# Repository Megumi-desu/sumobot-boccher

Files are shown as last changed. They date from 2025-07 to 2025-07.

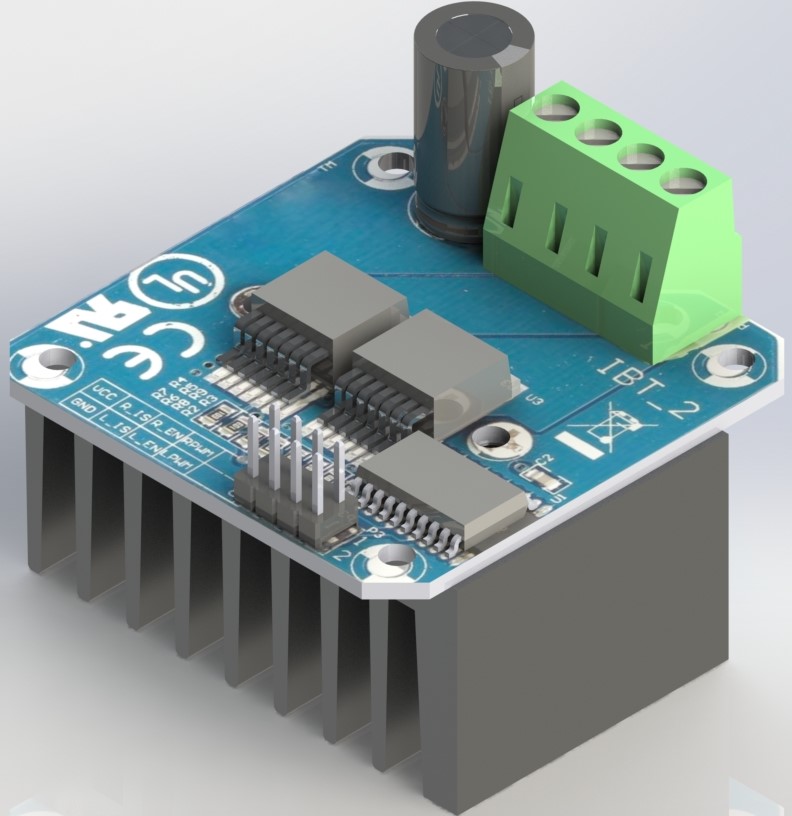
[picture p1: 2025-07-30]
Mechanic Design/BTS7960 43A HIGH POWER H BRIDGE MODULE.JPG

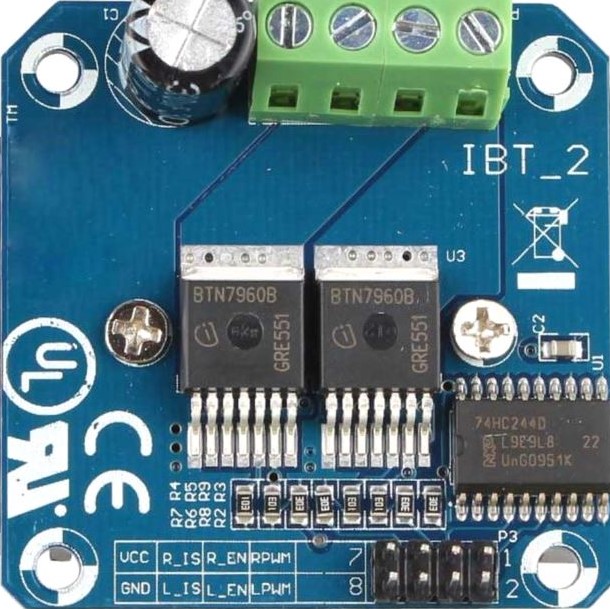
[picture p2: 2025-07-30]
Mechanic Design/TOP VIEW, BTS7960 43A HIGH POWER H BRIDGE MODULE.JPG

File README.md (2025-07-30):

# 🥊 SumoBot-Boccher  
**Arduino IDE Code for a 2-Wheel ESP32 Sumo Robot – Full RC Control**

> Ready-to-win firmware for TechnoCorner 2025!  
> Built around **ESP32 + L298N Dual H-Bridge + 2.4 GHz RC Rx/Tx**

---

## 📁 Repository Structure
```
sumobot-boccher/
├── README.md               ← You are here
├── boccher_v3_RC/          ← Final release v3 (RC)
│   └── boccher_v3_RC.ino   
└── extras/                 ← CAD, tuning logs, etc
```

---

## 🧰 Hardware Stack
| Part | Model / Pinout |
|---|---|
| Microcontroller | **ESP32 DOIT DevKit v1** |
| Motor Driver | **L298N Dual H-Bridge** |
| Motors | **JGA25-370** 12 V 500 rpm (3 kg robot) |
| RC System | **4-CH 2.4 GHz (FlySky TX4 clone)** |
| Battery | 3 S Li-ion 11.1 V 2200 mAh |
| Chassis | 3 mm aluminium plate, 3D-printed wheels |

---

## 🔌 Quick Wiring
| L298N | ESP32 Pin | Function |
|---|---|---|
| IN1 | 32 | Right motor direction 1 |
| IN2 | 33 | Right motor direction 2 |
| ENA | 25 | Right PWM (Channel 0) |
| IN3 | 27 | Left motor direction 1 |
| IN4 | 14 | Left motor direction 2 |
| ENB | 12 | Left PWM (Channel 1) |

| RC Rx | ESP32 Pin | Channel |
|---|---|---|
| CH1 | 5 | **Steering** |
| CH2 | 17 | **Throttle** |
| CH3 | 16 | **Rotate mode switch** |
| CH4 | 4 | **Emergency stop** |

> ⚡ Power the L298N logic from **5 V** rail, **NOT** 3.3 V.

---

## 🚀 Flash & Run
1. Install **Arduino IDE 2.x** with ESP32 board package (`esp32 by Espressif`).
2. Clone or download this repo.
3. Open `boccher_v2_RC/boccher_v3_RC.ino`.
4. Select:
   - Board: `ESP32 Dev Module`
   - Upload Speed: `921600`
   - Port: your COMx / ttyUSBx
5. Upload.
6. Power on the robot **then** the RC transmitter.
7. Open Serial Monitor @ 115 200 baud to see live telemetry.

---

## 🎮 RC Control Logic
| Stick / Switch | Behavior |
|---|---|
| **Left stick (CH2)** | Throttle forward / backward |
| **Right stick (CH1)** | Steering (tank mixing) |
| **3-pos switch (CH3)** | Up = **Rotate mode**<br>Middle = Normal drive<br>Down = N/A |
| **Momentary switch (CH4)** | Press = **Emergency stop** |

---

## 🛠 Tuning & Calibration
Calibrate your own sticks once:
```cpp
calibrateRC();   // Uncomment line 367, upload, follow Serial prompts
```
The sketch will print new `RC_CHx_CENTER` values – paste them back into the defines.

---

## 🧪 Built-in Test Routines
```cpp
testMotors();    // Line 350 → Full L298N motor test forward / backward
```
Great first-run sanity check.

---

## 🖥 Serial Debug Output (500 ms)
```
========== DEBUG INFO ==========
RC Connected: YES
Current Mode: NORMAL_DRIVE
--- RC Channels (Raw) ---
CH1 (Steering): 1670 | Mapped: 80
CH2 (Throttle): 1350 | Mapped: -110
CH3 (Rotate): 1500
CH4 (E-Stop): 1900
--- Motor Speeds ---
Right Motor: -190
Left Motor: -30
...
```

---

## 🏆 Competition Tips
- Set `speedMultiplier` (line 50) to 70–80 % during practice, 100 % on fight day.  
- Use **CH4 emergency stop** for instant failsafe.  
- Enable **debugMode = false** before matches to reduce latency.

---

## 🤝 Contributions & Forks
Pull requests welcome!  
🪲 Issues → GitHub Issues tab  
📸 Tag us on Instagram `#bocchersumo`

---

## 📄 License
MIT – do whatever you want, just mention the team 😉

---

**Built with ❤️ by Boccher Team – TechnoCorner 2025**  
> “*The ring is ours, the code is open.*”

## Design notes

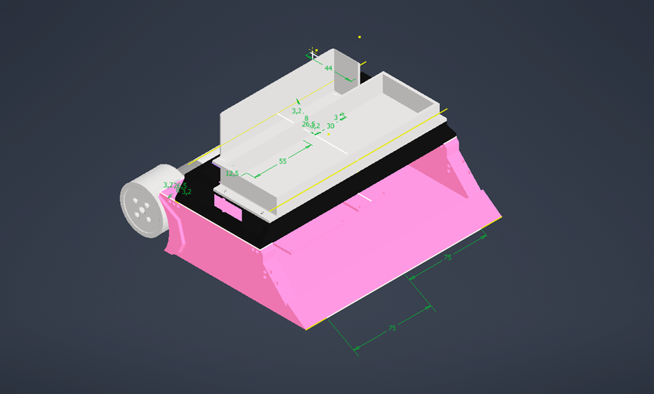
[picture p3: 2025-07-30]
design.png

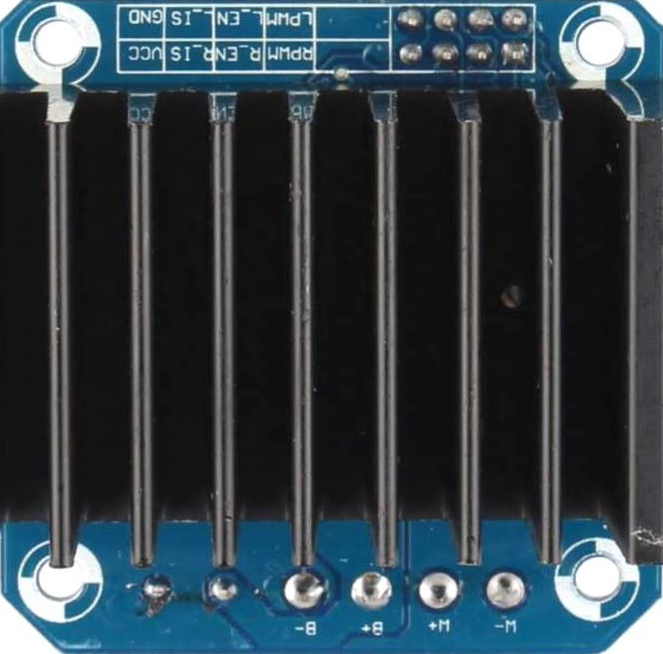
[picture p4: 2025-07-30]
Mechanic Design/BOTTOM VIEW, BTS7960 43A HIGH POWER H BRIDGE MODULE.JPG

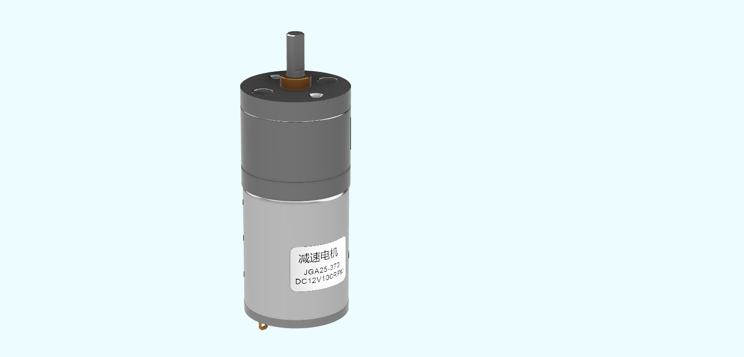
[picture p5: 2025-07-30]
Mechanic Design/JGA25-370 .png

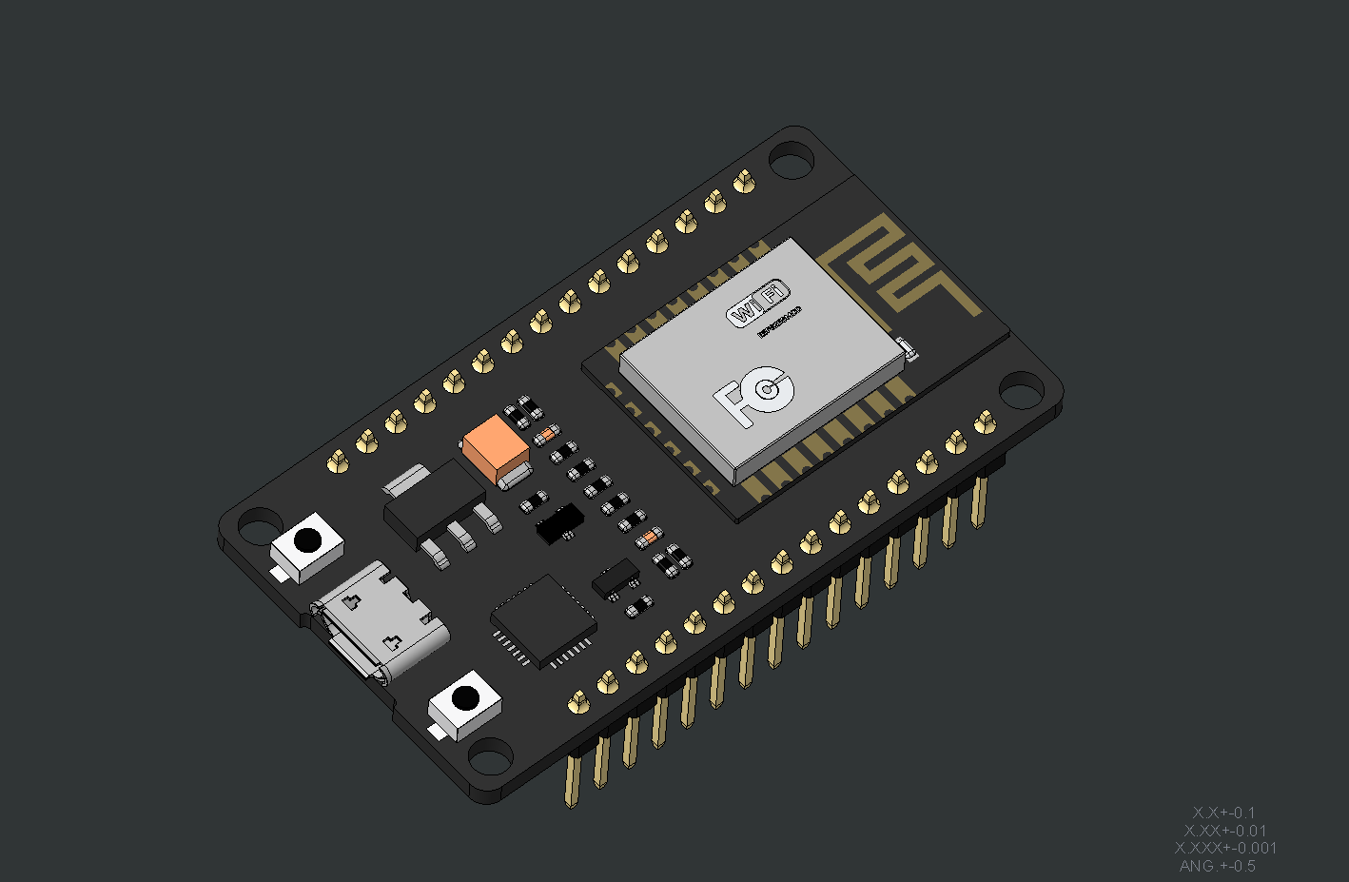
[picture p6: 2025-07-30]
Mechanic Design/esp32_dev_kit_v1.png

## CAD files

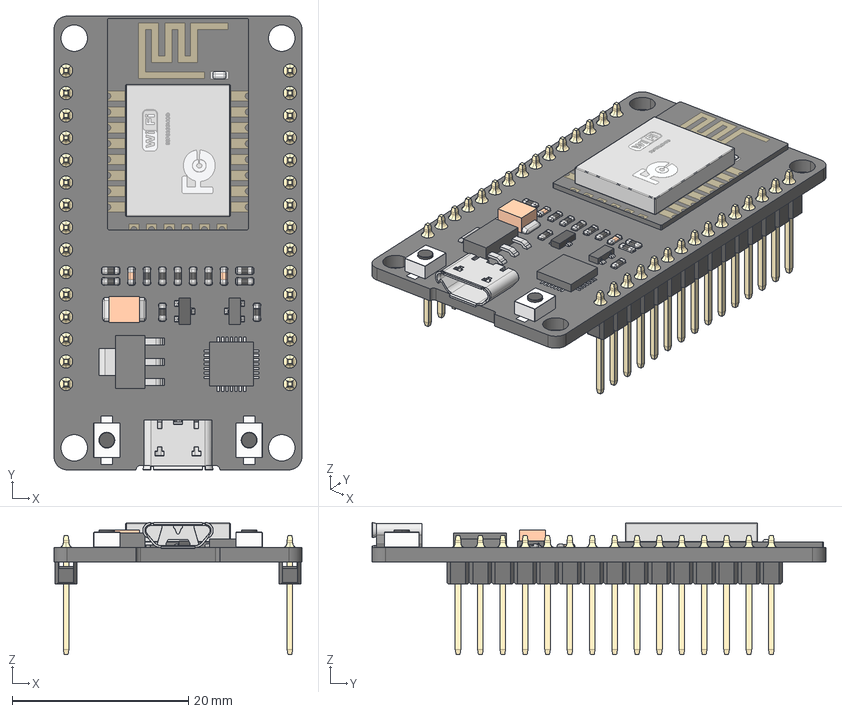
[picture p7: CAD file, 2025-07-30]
Mechanic Design/esp32_dev_kit_v1_asm.stp
28.1 x 51.5 x 15.0 mm
PCB
PIN x 30
WIFI_CARD_2
RECTANGULARCHIP_2
MICROCHIP_2
TANCHIP_2
TRANSISTOR_3-LEG_2
RESISTOR1_2 x 11
RESISTOR2-32_2 x 2
TRANSISTOR_3-LEG2_2
BUTTONFLASH-13_2 x 2
BUTTONFLASH-14_2 x 2
USB_SOCKET_2

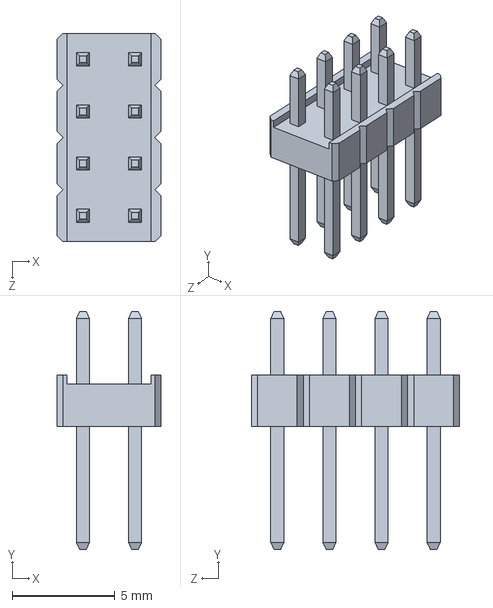
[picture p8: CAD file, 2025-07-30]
Mechanic Design/8 PIN HEADER, IC, BTS7960 43A HIGH POWER H BRIDGE MODULE.SLDPRT
5.08 x 11.6 x 10.2 mm

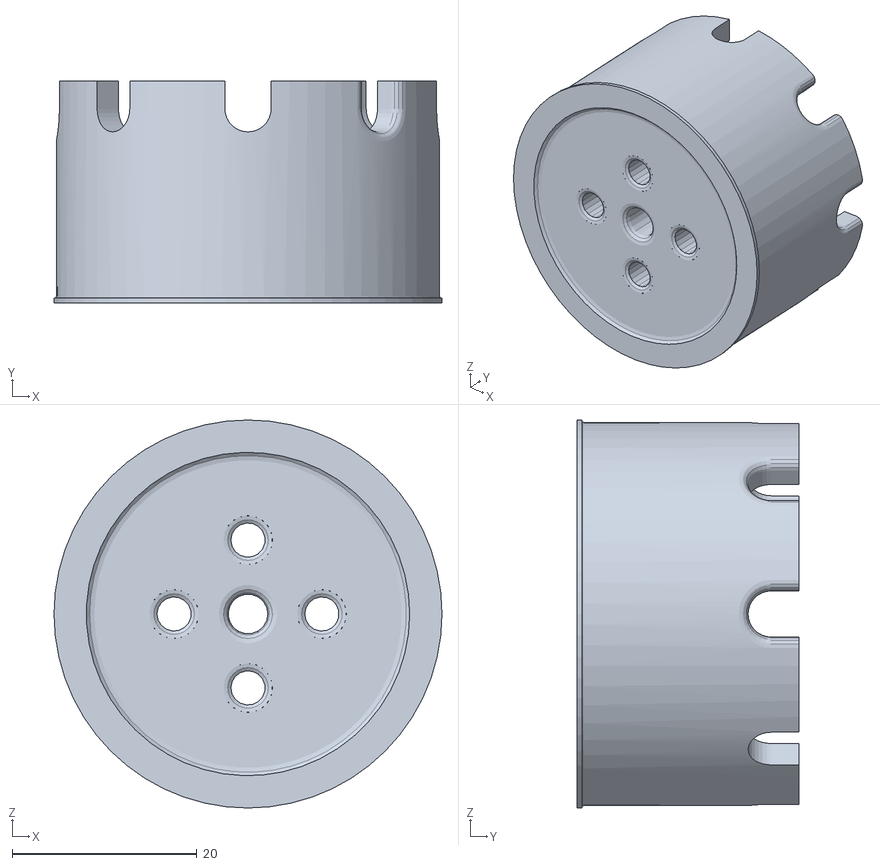
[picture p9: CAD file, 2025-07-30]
Mechanic Design/rodaa.stl
42.0 x 24.0 x 42.0

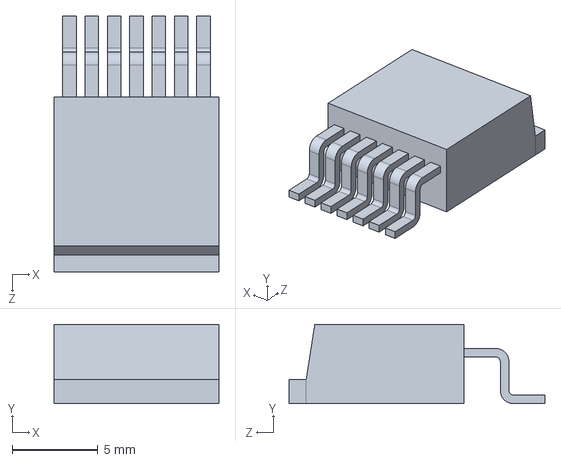
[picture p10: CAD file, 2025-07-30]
Mechanic Design/BTN7960 IC, BTS7960 43A HIGH POWER H BRIDGE MODULE.SLDPRT
9.60 x 4.60 x 14.9 mm

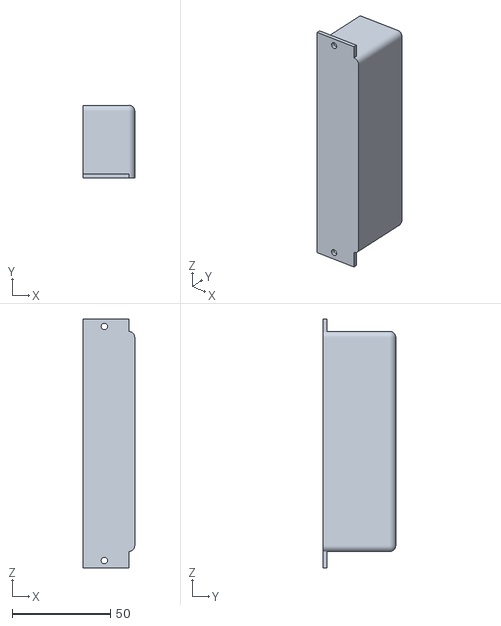
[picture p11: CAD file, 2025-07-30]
Mechanic Design/batre.stl
26.3 x 37.0 x 126.9

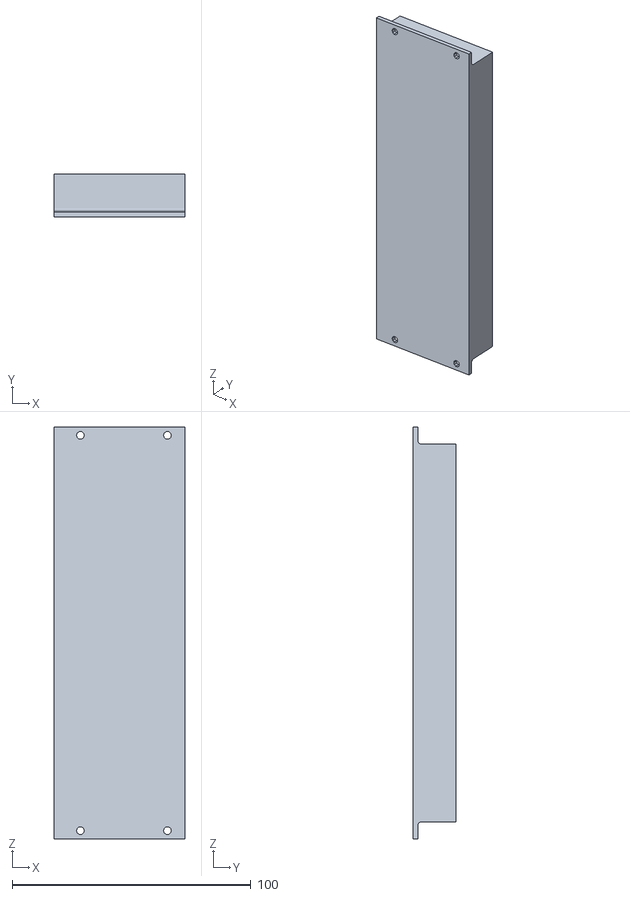
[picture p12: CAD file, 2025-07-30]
Mechanic Design/beban.stl
54.8 x 18.0 x 172.7

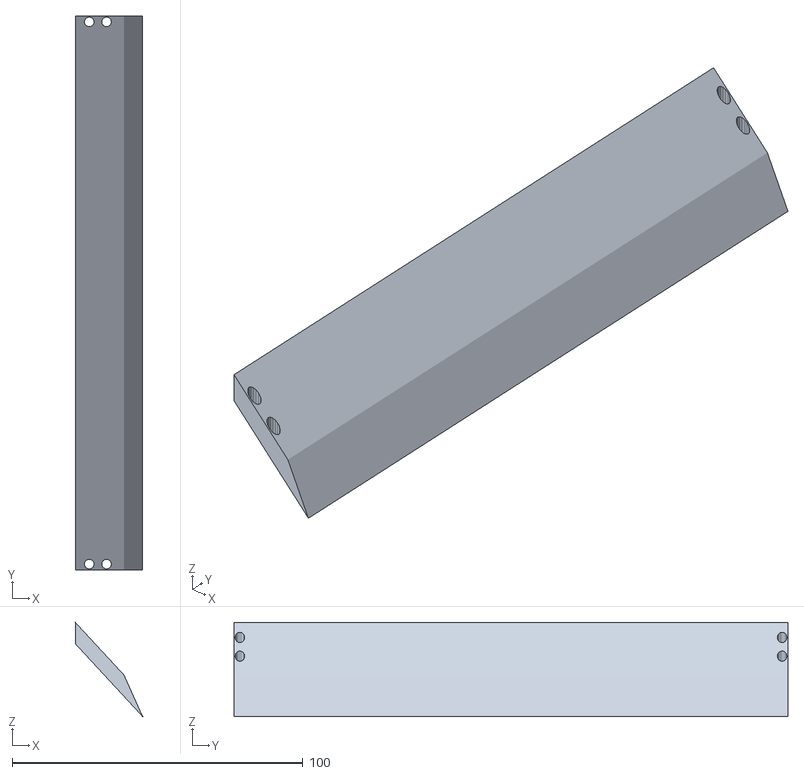
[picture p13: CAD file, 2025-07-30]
Mechanic Design/blade.stl
23.1 x 190.7 x 32.4

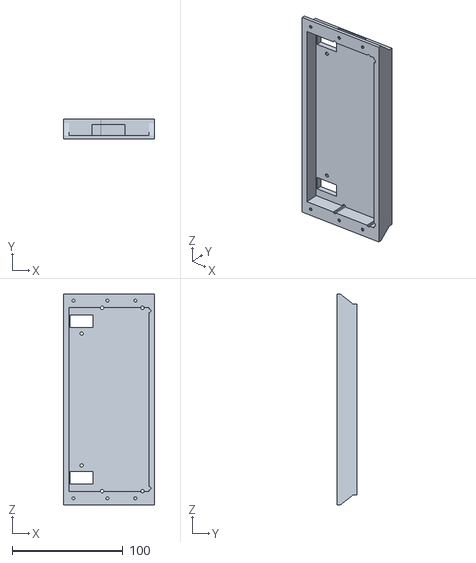
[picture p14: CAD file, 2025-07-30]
Mechanic Design/ataap.stl
82.5 x 18.0 x 190.7

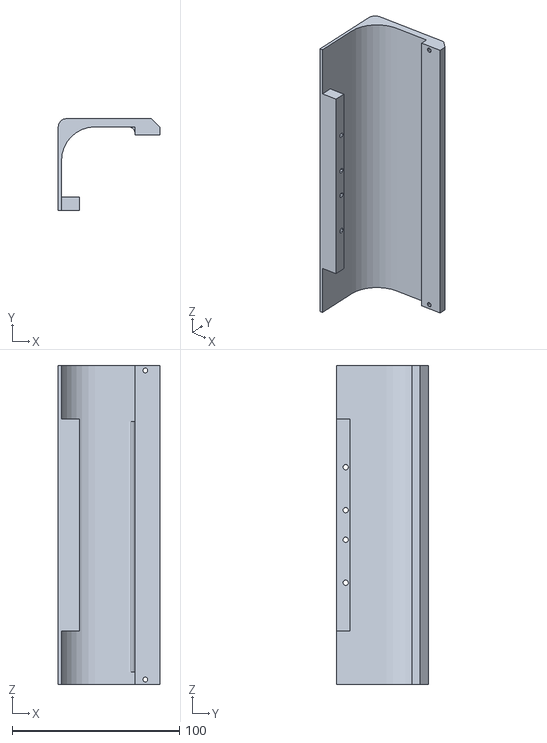
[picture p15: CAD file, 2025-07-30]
Mechanic Design/bumper belakang.stl
60.7 x 55.0 x 190.7

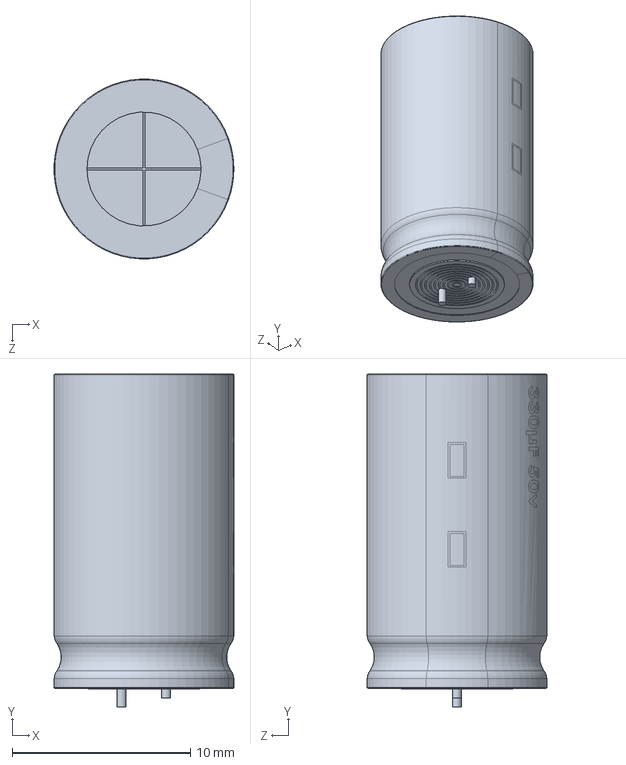
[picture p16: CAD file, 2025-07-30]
Mechanic Design/ALUMINUM ELECTROLYTIC CAPACITOR, 330 uF, BTS7960 43A HIGH POWER H BRIDGE MODULE.SLDPRT
10.1 x 18.7 x 10.1 mm

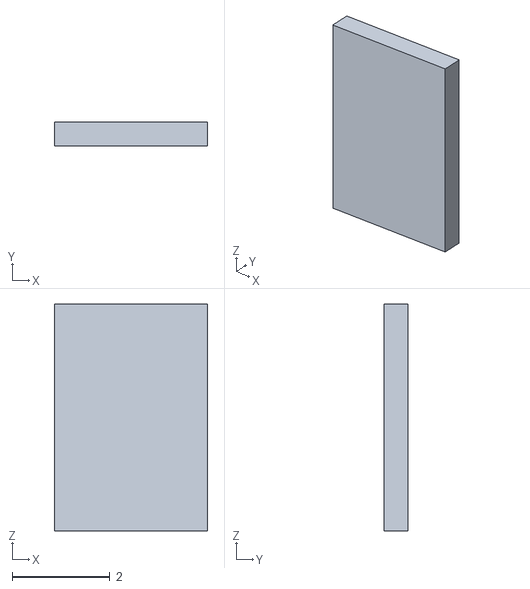
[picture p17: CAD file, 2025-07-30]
Mechanic Design/coba print.stl
3.13 x 0.5 x 4.64

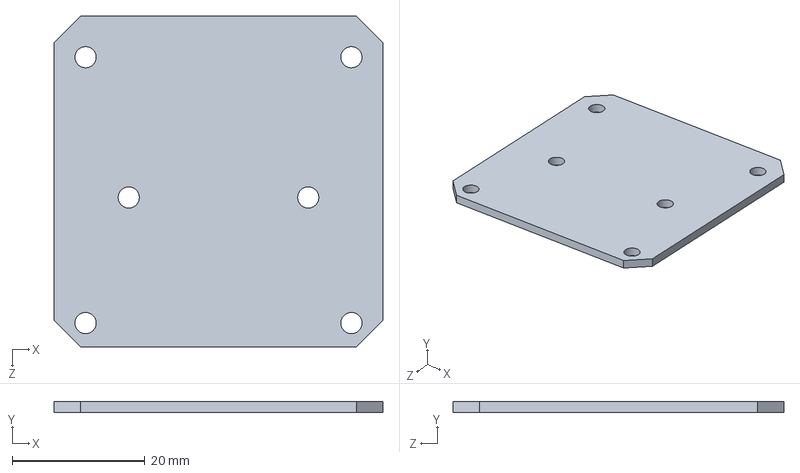
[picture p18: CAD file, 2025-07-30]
Mechanic Design/PCB, BTS7960 43A HIGH POWER H BRIDGE MODULE.SLDPRT
49.5 x 1.70 x 49.8 mm

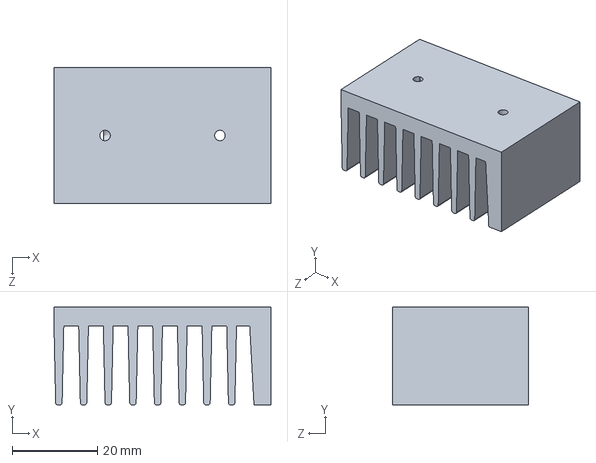
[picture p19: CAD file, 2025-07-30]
Mechanic Design/HEATSINK, BTS7960 43A HIGH POWER H BRIDGE MODULE.SLDPRT
51.0 x 23.0 x 32.0 mm

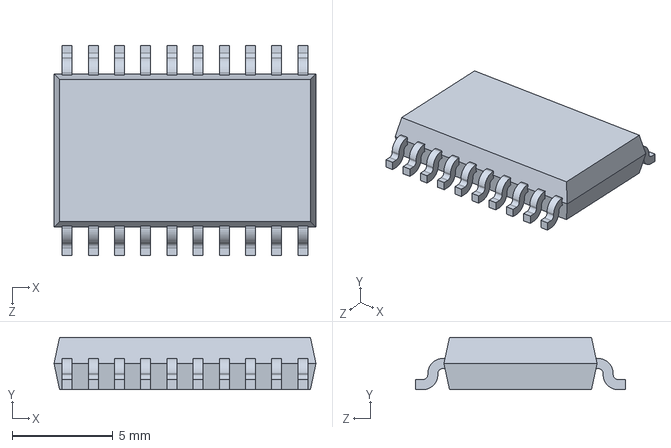
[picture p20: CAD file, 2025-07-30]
Mechanic Design/NXP 74HC244D, BUFFER AND LINE DRIVER, BTS7960 43A HIGH POWER H BRIDGE MODULE.SLDPRT
13.0 x 2.60 x 10.4 mm

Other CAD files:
Mechanic Design/bracket bener.stl
Mechanic Design/BTS7960 43A HIGH POWER H BRIDGE MODULE.STEP
Mechanic Design/roda.stl
Mechanic Design/atap.stl
Mechanic Design/,.ipt
Mechanic Design/BTS7960 43A HIGH POWER H BRIDGE MODULE.SLDASM
Mechanic Design/BTS7960 43A HIGH POWER H BRIDGE MODULE.x_b
Mechanic Design/EUROSTYLE TERMINAL BLOCK 2 POS 5.0 MM RA PLUG, BTS7960 43A HIGH POWER H BRIDGE MODULE.SLDPRT
Mechanic Design/JGA25-370 .step
Mechanic Design/OldVersions/atap.0003.ipt
Mechanic Design/OldVersions/bann.0002.ipt
Mechanic Design/OldVersions/base.0007.ipt
Mechanic Design/OldVersions/batre.0001.ipt
Mechanic Design/OldVersions/blade.0003.ipt
Mechanic Design/OldVersions/bracket bener.0003.ipt
Mechanic Design/OldVersions/bracket jga.0001.ipt
Mechanic Design/OldVersions/bumper belakang.0001.ipt
Mechanic Design/OldVersions/hub 4mm.0001.ipt
Mechanic Design/OldVersions/roda.0001.ipt
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

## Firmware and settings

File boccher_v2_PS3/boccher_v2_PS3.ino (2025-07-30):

/*
 *  SumoBot 3kg TechnoCorner 2025 - PS3 Controller Version
 *  Ready to Win for TechnoCorner 2025!!
 *  Boccher Team
 *  Component : Motor JGA25-370 dengan driver terintegrasi, PS3 Controller, ESP32 Doit Devkit V1
 *  
 *  Library yang diperlukan:
 *  - PS3Controller by Jeffery Pernis (install via Library Manager)
 *  
 *  Cara pairing PS3 Controller:
 *  1. Upload kode ini ke ESP32
 *  2. Buka Serial Monitor
 *  3. Hubungkan PS3 controller ke komputer via USB
 *  4. Tekan tombol PS pada controller
 *  5. Controller akan otomatis terhubung ke ESP32
 */

#include <Ps3Controller.h>

// Motor kiri
#define MOTOR_KIRI_CW  32
#define MOTOR_KIRI_CCW 33

// Motor kanan
#define MOTOR_KANAN_CW  18
#define MOTOR_KANAN_CCW 19

// PWM Configuration
#define PWM_FREQUENCY          1000  // Reduced frequency for motor drivers
#define PWM_RESOLUTION         8
#define PWM_CHANNEL_KIRI_CW    0
#define PWM_CHANNEL_KIRI_CCW   1
#define PWM_CHANNEL_KANAN_CW   2
#define PWM_CHANNEL_KANAN_CCW  3

// Control parameters
#define STICK_DEADZONE 15      // Deadzone untuk analog stick (0-128)
#define MAX_STICK_VALUE 128    // Maximum value dari analog stick
int maxSpeed = 255;
int minSpeed = 60;            // Minimum speed untuk motor response yang baik

// Connection status
bool isPS3Connected = false;
unsigned long lastPS3Signal = 0;
#define PS3_TIMEOUT 3000      // PS3 signal timeout (milliseconds)

// LED status
#define LED_BUILTIN 2
unsigned long lastBlinkTime = 0;
bool ledState = false;

// Control mode
enum ControlMode {
  NORMAL_MODE,
  ROTATE_MODE,
  EMERGENCY_STOP
};
ControlMode currentMode = NORMAL_MODE;

// PS3 Controller callback functions
void onConnect() {
  Serial.println("PS3 Controller terhubung!");
  isPS3Connected = true;
  lastPS3Signal = millis();
  
  // Set LED warna untuk indikasi koneksi (opsional)
  Ps3.setLed(1, 0, 0); // LED Player 1 merah
}

void onDisconnect() {
  Serial.println("PS3 Controller terputus!");
  isPS3Connected = false;
  stopMotors();
}

void notify() {
  // Update timestamp setiap kali ada input
  lastPS3Signal = millis();
  
  // Emergency stop check (tombol SELECT)
  if (Ps3.data.button.select) {
    currentMode = EMERGENCY_STOP;
    stopMotors();
    Serial.println("EMERGENCY STOP!");
    return;
  }
  
  // Mode switching dengan tombol START
  if (Ps3.data.button.start) {
    static unsigned long lastModeSwitch = 0;
    if (millis() - lastModeSwitch > 500) { // Debounce 500ms
      if (currentMode == NORMAL_MODE) {
        currentMode = ROTATE_MODE;
        Serial.println("Mode: ROTATE");
        Ps3.setLed(0, 1, 0); // LED hijau untuk rotate mode
      } else {
        currentMode = NORMAL_MODE;
        Serial.println("Mode: NORMAL");
        Ps3.setLed(1, 0, 0); // LED merah untuk normal mode
      }
      lastModeSwitch = millis();
    }
  }
  
  // Reset emergency stop dengan tombol PS
  if (Ps3.data.button.ps && currentMode == EMERGENCY_STOP) {
    currentMode = NORMAL_MODE;
    Serial.println("Emergency stop direset");
    Ps3.setLed(1, 0, 0); // LED merah untuk normal mode
  }
}

void setup() {
  Serial.begin(115200);
  
  // Setup motor pins sebagai output
  pinMode(MOTOR_KIRI_CW, OUTPUT);
  pinMode(MOTOR_KIRI_CCW, OUTPUT);
  pinMode(MOTOR_KANAN_CW, OUTPUT);
  pinMode(MOTOR_KANAN_CCW, OUTPUT);
  pinMode(LED_BUILTIN, OUTPUT);
  digitalWrite(LED_BUILTIN, LOW);

  // Setup PWM channels
  ledcSetup(PWM_CHANNEL_KIRI_CW, PWM_FREQUENCY, PWM_RESOLUTION);
  ledcSetup(PWM_CHANNEL_KIRI_CCW, PWM_FREQUENCY, PWM_RESOLUTION);
  ledcSetup(PWM_CHANNEL_KANAN_CW, PWM_FREQUENCY, PWM_RESOLUTION);
  ledcSetup(PWM_CHANNEL_KANAN_CCW, PWM_FREQUENCY, PWM_RESOLUTION);

  ledcAttachPin(MOTOR_KIRI_CW, PWM_CHANNEL_KIRI_CW);
  ledcAttachPin(MOTOR_KIRI_CCW, PWM_CHANNEL_KIRI_CCW);
  ledcAttachPin(MOTOR_KANAN_CW, PWM_CHANNEL_KANAN_CW);
  ledcAttachPin(MOTOR_KANAN_CCW, PWM_CHANNEL_KANAN_CCW);

  // Initialize PS3 Controller
  Ps3.attach(notify);
  Ps3.attachOnConnect(onConnect);
  Ps3.attachOnDisconnect(onDisconnect);
  Ps3.begin("01:02:03:04:05:06"); // MAC address ESP32 (akan otomatis terdeteksi)
  
  stopMotors();
  
  Serial.println("Robot Sumo PS3 Control Ready!");
  Serial.println("Motor: JGA25-370 dengan driver terintegrasi");
  Serial.println("Menunggu koneksi PS3 Controller...");
  Serial.println("");
  Serial.println("Kontrol:");
  Serial.println("- Left Stick (Y): Maju/mundur");
  Serial.println("- Right Stick (X): Belok kiri/kanan");
  Serial.println("- START: Toggle Normal/Rotate mode");
  Serial.println("  * Normal: Maju/mundur + belok bersamaan");
  Serial.println("  * Rotate: Hanya rotate tanpa maju/mundur");
  Serial.println("- SELECT: Emergency stop");
  Serial.println("- PS Button: Reset emergency stop");
  Serial.println("- L1/R1: Turbo speed");
  Serial.println("");
}

void loop() {
  // Check PS3 connection status
  checkPS3Connection();
  
  // Handle LED status
  handleLEDStatus();
  
  // Process PS3 commands if connected and not in emergency stop
  if (isPS3Connected && currentMode != EMERGENCY_STOP) {
    processPS3Commands();
  } else if (currentMode == EMERGENCY_STOP) {
    stopMotors(); // Pastikan motor berhenti saat emergency stop
  }
  
  // Debug output (comment out untuk kompetisi)
  static unsigned long lastDebugTime = 0;
  if (millis() - lastDebugTime >= 1000) {
    lastDebugTime = millis();
    if (isPS3Connected) {
      Serial.print("LX: "); Serial.print(Ps3.data.analog.stick.lx);
      Serial.print(" LY: "); Serial.print(Ps3.data.analog.stick.ly);
      Serial.print(" RX: "); Serial.print(Ps3.data.analog.stick.rx);
      Serial.print(" RY: "); Serial.print(Ps3.data.analog.stick.ry);
      Serial.print(" Mode: ");
      if (currentMode == NORMAL_MODE) Serial.print("NORMAL");
      else if (currentMode == ROTATE_MODE) Serial.print("ROTATE");
      else Serial.print("EMERGENCY");
      Serial.println();
    }
  }
  
  delay(20);
}

void checkPS3Connection() {
  unsigned long currentTime = millis();
  
  // Check timeout untuk koneksi PS3
  if (isPS3Connected && (currentTime - lastPS3Signal > PS3_TIMEOUT)) {
    Serial.println("PS3 Controller timeout!");
    isPS3Connected = false;
    stopMotors();
  }
}

void handleLEDStatus() {
  if (isPS3Connected) {
    // Blink LED when connected
    unsigned long currentTime = millis();
    if (currentTime - lastBlinkTime >= 500) {
      lastBlinkTime = currentTime;
      ledState = !ledState;
      digitalWrite(LED_BUILTIN, ledState);
    }
  } else {
    // LED off when disconnected
    digitalWrite(LED_BUILTIN, LOW);
  }
}

void processPS3Commands() {
  // Check untuk turbo speed (L1 atau R1)
  int speedMultiplier = 1;
  if (Ps3.data.button.l1 || Ps3.data.button.r1) {
    speedMultiplier = 2; // Turbo mode
  }
  
  // LEFT STICK: Kontrol maju/mundur saja (Y-axis)
  int throttle = -Ps3.data.analog.stick.ly; // Invert Y axis (up = positive)
  
  // RIGHT STICK: Kontrol belok/rotate (X-axis)
  int steering = Ps3.data.analog.stick.rx;  // Left = negative, Right = positive
  
  // Apply deadzone
  if (abs(throttle) < STICK_DEADZONE) throttle = 0;
  if (abs(steering) < STICK_DEADZONE) steering = 0;
  
  // Convert dari stick value (-128 to 127) ke motor speed
  throttle = map(throttle, -MAX_STICK_VALUE, MAX_STICK_VALUE, -maxSpeed, maxSpeed);
  steering = map(steering, -MAX_STICK_VALUE, MAX_STICK_VALUE, -maxSpeed, maxSpeed);
  
  // Apply speed multiplier
  throttle *= speedMultiplier;
  steering *= speedMultiplier;
  
  // Constrain values
  throttle = constrain(throttle, -maxSpeed, maxSpeed);
  steering = constrain(steering, -maxSpeed, maxSpeed);
  
  if (currentMode == NORMAL_MODE) {
    // Normal mode: Kombinasi maju/mundur + belok
    moveRobot(throttle, steering);
    
  } else if (currentMode == ROTATE_MODE) {
    // Rotate mode: Hanya rotate tanpa maju/mundur
    if (abs(steering) > 0) {
      if (steering > 0) {
        rotateRight(abs(steering));
      } else {
        rotateLeft(abs(steering));
      }
    } else {
      stopMotors();
    }
  }
}

void moveRobot(int throttle, int steering) {
  // Tank drive mixing
  int leftMotorSpeed  = throttle + steering;
  int rightMotorSpeed = throttle - steering;

  // Constrain speeds
  leftMotorSpeed  = constrain(leftMotorSpeed, -maxSpeed, maxSpeed);
  rightMotorSpeed = constrain(rightMotorSpeed, -maxSpeed, maxSpeed);

  setMotorSpeed(leftMotorSpeed, rightMotorSpeed);
}

void setMotorSpeed(int leftSpeed, int rightSpeed) {
  // Motor kiri
  // Untuk maju: motor kiri harus berputar CCW
  // Untuk mundur: motor kiri harus berputar CW
  if (leftSpeed > 0) {
    // Maju - CCW
    ledcWrite(PWM_CHANNEL_KIRI_CW, 0);
    ledcWrite(PWM_CHANNEL_KIRI_CCW, leftSpeed);
  } else if (leftSpeed < 0) {
    // Mundur - CW
    ledcWrite(PWM_CHANNEL_KIRI_CW, -leftSpeed);
    ledcWrite(PWM_CHANNEL_KIRI_CCW, 0);
  } else {
    // Stop
    ledcWrite(PWM_CHANNEL_KIRI_CW, 0);
    ledcWrite(PWM_CHANNEL_KIRI_CCW, 0);
  }

  // Motor kanan
  // Untuk maju: motor kanan harus berputar CW
  // Untuk mundur: motor kanan harus berputar CCW
  if (rightSpeed > 0) {
    // Maju - CW
    ledcWrite(PWM_CHANNEL_KANAN_CW, rightSpeed);
    ledcWrite(PWM_CHANNEL_KANAN_CCW, 0);
  } else if (rightSpeed < 0) {
    // Mundur - CCW
    ledcWrite(PWM_CHANNEL_KANAN_CW, 0);
    ledcWrite(PWM_CHANNEL_KANAN_CCW, -rightSpeed);
  } else {
    // Stop
    ledcWrite(PWM_CHANNEL_KANAN_CW, 0);
    ledcWrite(PWM_CHANNEL_KANAN_CCW, 0);
  }
}

void rotateLeft(int speed) {
  // Rotate left: motor kiri mundur (CW), motor kanan maju (CW)
  ledcWrite(PWM_CHANNEL_KIRI_CW, speed);   // Motor kiri CW (mundur)
  ledcWrite(PWM_CHANNEL_KIRI_CCW, 0);
  ledcWrite(PWM_CHANNEL_KANAN_CW, speed);  // Motor kanan CW (maju)
  ledcWrite(PWM_CHANNEL_KANAN_CCW, 0);
}

void rotateRight(int speed) {
  // Rotate right: motor kiri maju (CCW), motor kanan mundur (CCW)
  ledcWrite(PWM_CHANNEL_KIRI_CW, 0);
  ledcWrite(PWM_CHANNEL_KIRI_CCW, speed);  // Motor kiri CCW (maju)
  ledcWrite(PWM_CHANNEL_KANAN_CW, 0);
  ledcWrite(PWM_CHANNEL_KANAN_CCW, speed); // Motor kanan CCW (mundur)
}

void stopMotors() {
  ledcWrite(PWM_CHANNEL_KIRI_CW, 0);
  ledcWrite(PWM_CHANNEL_KIRI_CCW, 0);
  ledcWrite(PWM_CHANNEL_KANAN_CW, 0);
  ledcWrite(PWM_CHANNEL_KANAN_CCW, 0);
}

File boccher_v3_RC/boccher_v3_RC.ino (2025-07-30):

/*
 *  SumoBot 3kg TechnoCorner 2025 - RC Control Version dengan L298N Driver
 *  Ready to Win for TechnoCorner 2025!!
 *  Boccher Team - L298N VERSION
 *  Component : Motor JGA25-370 dengan driver L298N, RC Receiver 2.4GHz, ESP32 Doit Devkit V1
 *  RC Transmitter: TX4 2.4 GHz 4CH
 */

// L298N Driver Motor Kanan
#define MOTOR_KANAN_IN1 32   
#define MOTOR_KANAN_IN2 33     
#define MOTOR_KANAN_ENA 25   

// L298N Driver Motor Kiri
#define MOTOR_KIRI_IN3 27    
#define MOTOR_KIRI_IN4 14    
#define MOTOR_KIRI_ENB 12    

// RC Receiver pins
#define RC_CH1_PIN 5   // Steering
#define RC_CH2_PIN 17  // Throttle
#define RC_CH3_PIN 16  // Switch untuk mode rotate
#define RC_CH4_PIN 4   // Emergency stop

// PWM Configuration untuk L298N Enable pins
#define PWM_FREQUENCY          1000
#define PWM_RESOLUTION         8
#define PWM_CHANNEL_KANAN      0    // Channel PWM untuk ENA (motor kanan)
#define PWM_CHANNEL_KIRI       1    // Channel PWM untuk ENB (motor kiri)

// RC signal parameters - SAMA SEPERTI SEBELUMNYA
#define RC_MIN_PULSE 1100    
#define RC_MAX_PULSE 1900    
#define RC_MID_PULSE 1500
#define RC_DEADZONE 50

// #define THROTTLE_MAX_POINT 1320  // 3/5 dari range (1500-1100)*0.6 + 1100
// #define THROTTLE_MIN_POINT 1680  // 3/5 dari range (1900-1500)*0.6 + 1500
// #define STEERING_MAX_POINT 1320  // 3/5 dari range
// #define STEERING_MIN_POINT 1680  // 3/5 dari range

#define RC_CH1_CENTER 1500
#define RC_CH2_CENTER 1500

// Motor parameters
int maxSpeed = 255;          
int minSpeed = 20;           
int speedMultiplier = 100;   
bool isRCConnected = false;
unsigned long lastRCSignal = 0;
#define RC_TIMEOUT 1000

// LED status
#define LED_BUILTIN 2
unsigned long lastBlinkTime = 0;
bool ledState = false;

// Debug mode
bool debugMode = true;
unsigned long lastDebugTime = 0;
#define DEBUG_INTERVAL 500   

// RC channel values
volatile unsigned long rc_ch1_start = 0;
volatile unsigned long rc_ch2_start = 0;
volatile unsigned long rc_ch3_start = 0;
volatile unsigned long rc_ch4_start = 0;

volatile int rc_ch1_value = RC_CH1_CENTER;  // Steering
volatile int rc_ch2_value = RC_CH2_CENTER;  // Throttle
volatile int rc_ch3_value = RC_MID_PULSE;   // Rotate mode
volatile int rc_ch4_value = RC_MAX_PULSE;   // Emergency stop (default HIGH)

// Motor status untuk debug
int currentFixRightSpeed = 0;
int currentFixLeftSpeed = 0;
String currentMode = "STOP";
int mappedThrottle = 0;
int mappedSteering = 0;

// RC Channel interrupt handlers - SAMA SEPERTI SEBELUMNYA
void IRAM_ATTR readRC_CH1() {
  if (digitalRead(RC_CH1_PIN) == HIGH) {
    rc_ch1_start = micros();
  } else {
    if (rc_ch1_start != 0) {
      unsigned long pulseWidth = micros() - rc_ch1_start;
      if (pulseWidth >= RC_MIN_PULSE && pulseWidth <= RC_MAX_PULSE) {
        rc_ch1_value = pulseWidth;
        lastRCSignal = millis();
      }
      rc_ch1_start = 0;
    }
  }
}

void IRAM_ATTR readRC_CH2() {
  if (digitalRead(RC_CH2_PIN) == HIGH) {
    rc_ch2_start = micros();
  } else {
    if (rc_ch2_start != 0) {
      unsigned long pulseWidth = micros() - rc_ch2_start;
      if (pulseWidth >= RC_MIN_PULSE && pulseWidth <= RC_MAX_PULSE) {
        rc_ch2_value = pulseWidth;
        lastRCSignal = millis();
      }
      rc_ch2_start = 0;
    }
  }
}

void IRAM_ATTR readRC_CH3() {
  if (digitalRead(RC_CH3_PIN) == HIGH) {
    rc_ch3_start = micros();
  } else {
    if (rc_ch3_start != 0) {
      unsigned long pulseWidth = micros() - rc_ch3_start;
      if (pulseWidth >= RC_MIN_PULSE && pulseWidth <= RC_MAX_PULSE) {
        rc_ch3_value = pulseWidth;
        lastRCSignal = millis();
      }
      rc_ch3_start = 0;
    }
  }
}

void IRAM_ATTR readRC_CH4() {
  if (digitalRead(RC_CH4_PIN) == HIGH) {
    rc_ch4_start = micros();
  } else {
    if (rc_ch4_start != 0) {
      unsigned long pulseWidth = micros() - rc_ch4_start;
      if (pulseWidth >= RC_MIN_PULSE && pulseWidth <= RC_MAX_PULSE) {
        rc_ch4_value = pulseWidth;
        lastRCSignal = millis();
      }
      rc_ch4_start = 0;
    }
  }
}

void setup() {
  Serial.begin(115200);
  delay(2000);  
  
  Serial.println("==========================================");
  Serial.println("  SUMOBOT RC CONTROL - L298N VERSION");
  Serial.println("==========================================");
  Serial.println("Motor Driver: L298N Dual H-Bridge");
  Serial.println("Channel Mapping:");
  Serial.println("CH1 = STEERING (Kiri-Kanan)");
  Serial.println("CH2 = THROTTLE (Maju-Mundur)");
  Serial.println("CH3 = ROTATE MODE (Optional)");
  Serial.println("CH4 = EMERGENCY STOP");
  Serial.println("==========================================");
  Serial.println("L298N Pin Connections:");
  Serial.println("Motor Kiri: IN3=27, IN4=14, ENB=12");
  Serial.println("Motor Kanan: IN1=32, IN2=33, ENA=25");
  Serial.println("==========================================");
  
  // Setup motor direction pins sebagai output
  pinMode(MOTOR_KANAN_IN1, OUTPUT);
  pinMode(MOTOR_KANAN_IN2, OUTPUT);
  pinMode(MOTOR_KIRI_IN3, OUTPUT);
  pinMode(MOTOR_KIRI_IN4, OUTPUT);
  pinMode(LED_BUILTIN, OUTPUT);
  digitalWrite(LED_BUILTIN, LOW);

  // Setup PWM channels untuk Enable pins L298N
  ledcSetup(PWM_CHANNEL_KANAN, PWM_FREQUENCY, PWM_RESOLUTION);
  ledcSetup(PWM_CHANNEL_KIRI, PWM_FREQUENCY, PWM_RESOLUTION);

  // Attach PWM ke Enable pins
  ledcAttachPin(MOTOR_KANAN_ENA, PWM_CHANNEL_KANAN);
  ledcAttachPin(MOTOR_KIRI_ENB, PWM_CHANNEL_KIRI);

  // Setup RC receiver pins
  pinMode(RC_CH1_PIN, INPUT);
  pinMode(RC_CH2_PIN, INPUT);
  pinMode(RC_CH3_PIN, INPUT);
  pinMode(RC_CH4_PIN, INPUT);

  // Attach interrupts for RC channels
  attachInterrupt(digitalPinToInterrupt(RC_CH1_PIN), readRC_CH1, CHANGE);
  attachInterrupt(digitalPinToInterrupt(RC_CH2_PIN), readRC_CH2, CHANGE);
  attachInterrupt(digitalPinToInterrupt(RC_CH3_PIN), readRC_CH3, CHANGE);
  attachInterrupt(digitalPinToInterrupt(RC_CH4_PIN), readRC_CH4, CHANGE);

  stopMotors();
  
  Serial.println("Setup completed! Waiting for RC signal...");
  Serial.println("Debug info will be displayed every 500ms");
  Serial.println("==========================================");
}

void loop() {
  // Check RC connection status
  checkRCConnection();
  
  // Handle LED status
  handleLEDStatus();
  
  // Enhanced debug output
  if (debugMode) {
    printDebugInfo();
  }
  
  // Process RC commands if connected
  if (isRCConnected) {
    processRCCommands();
  } else {
    if (currentMode != "DISCONNECTED") {
      stopMotors();
      currentMode = "DISCONNECTED";
    }
  }
  
  delay(10);
}

void checkRCConnection() {
  unsigned long currentTime = millis();
  
  if (currentTime - lastRCSignal < RC_TIMEOUT) {
    if (!isRCConnected) {
      isRCConnected = true;
      Serial.println("\n*** RC TRANSMITTER TERHUBUNG! ***");
    }
  } else {
    if (isRCConnected) {
      isRCConnected = false;
      Serial.println("\n*** RC TRANSMITTER TERPUTUS! ***");
      stopMotors();
    }
  }
}
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
